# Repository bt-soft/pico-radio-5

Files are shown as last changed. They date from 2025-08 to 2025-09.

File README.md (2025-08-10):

# Pico-Radio-5

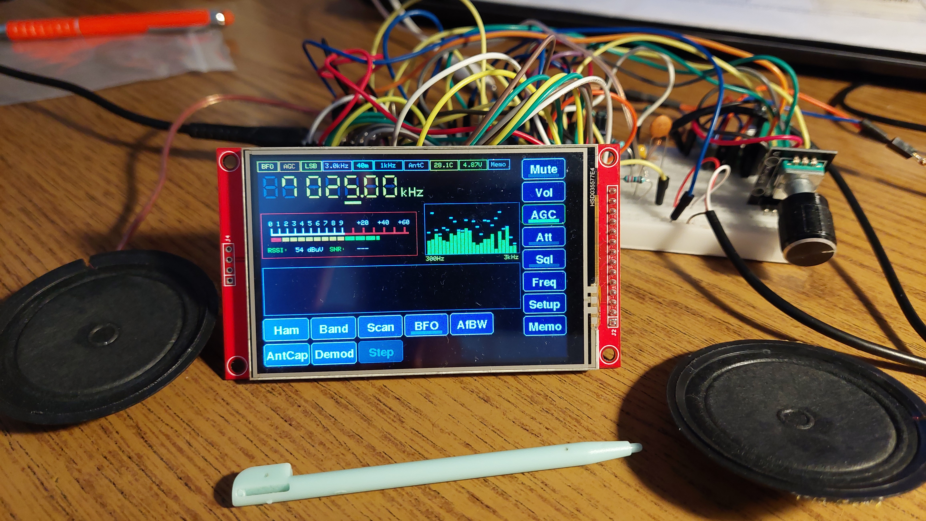
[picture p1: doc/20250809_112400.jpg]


## Hardver részletesen

A Pico-Radio-5 egy fejlett, több sávos rádióvevő, amely a Raspberry Pi Pico (RP2040) mikrokontroller köré épül. A főbb hardverelemek:

- **Raspberry Pi Pico**  
  ARM Cortex-M0+ dual-core MCU, 2MB flash, 264kB RAM, USB programozás.
- **SI4735 rádió IC**  
  Digitális rádióvevő chip, amely támogatja az FM (RDS), AM (MW, LW, SW) sávokat, digitális vezérléssel (I2C).
- **TFT érintőkijelző**  
  320x240 vagy 480x320 felbontású, színes, érintésérzékeny kijelző (TFT_eSPI driverrel).
- **Rotary encoder**  
  Mechanikus forgó kódoló, amely a frekvencia, hangerő, menük vezérlésére szolgál (kattintás érzékelés is).
- **Hangkimenet**  
  3.5mm jack vagy beépített hangszóró, SI4735 audio kimenet közvetlenül vagy erősítőn keresztül.
- **Akkumulátor mérés**  
  Feszültségosztóval a Pico ADC-n keresztül, töltöttség kijelzés.
- **EEPROM**  
  Állomásmemória, beállítások tartós tárolása.
- **Egyéb**  
  Nyomógombok, szenzorok (pl. hőmérséklet), LED-ek, opcionális bővítések.

A részletes kapcsolási rajzok, NYÁK-tervek a `doc/` mappában találhatók:
- [Kapcsolási rajz (PDF)](doc/pico-radio-5-sch.pdf)
- [NYÁK terv (PDF)](doc/pico-radio-5-pcb.pdf)
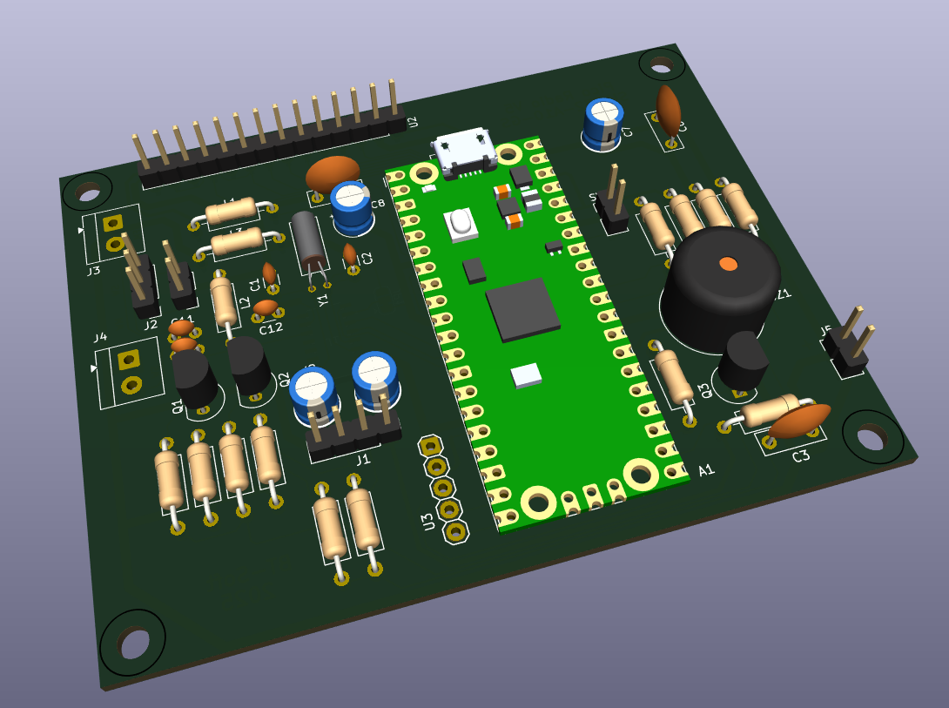
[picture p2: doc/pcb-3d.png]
NYÁK 3D)


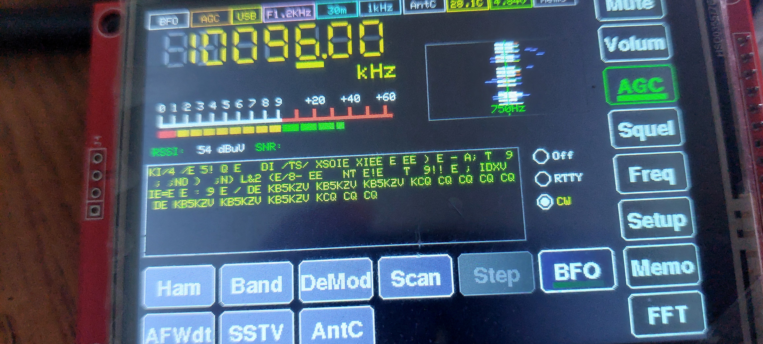
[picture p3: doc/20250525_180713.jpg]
Készülék fotó

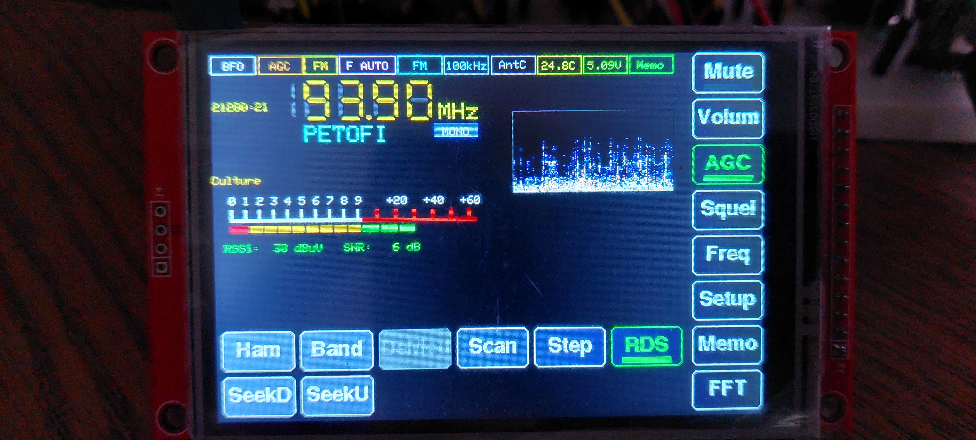
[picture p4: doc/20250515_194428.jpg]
Kijelző példa


## Szoftver részletesen

A szoftver PlatformIO környezetben, C++ nyelven, Arduino frameworkre épül. Főbb könyvtárak: PU2CLR SI4735, TFT_eSPI, RPI_PICO_TimerInterrupt.

### Fő funkciók

- **Rádió sávok**: FM (RDS), AM (MW, LW, SW), SSB/CW támogatás (ha SI4735 patch betöltve)
- **Állomáskeresés, finomhangolás**: automatikus és kézi keresés, lépésköz választás
- **Állomásmemória**: FM/AM/SW/LW sávonként, EEPROM-ban tárolva
- **RDS támogatás**: FM sávban állomásnév, rádiószöveg, PTY, óra
- **Grafikus kezelőfelület**: érintőképernyő, rotary encoder, menük, dialógusok, státuszsor
- **Képernyővédő**: animált frekvencia kijelzés, energiatakarékosság
- **Spektrumkijelzés**: FFT-alapú vizualizáció (ha támogatott)
- **Beállítások**: hangerő, sáv, lépésköz, kijelző fényerő, képernyővédő időzítés, stb.
- **Akkumulátor kijelzés**: töltöttség százalékban, színkódolva
- **Debug és diagnosztika**: soros porton részletes log, hibakereséshez

### Mappastruktúra

- `src/` – Fő forráskód (képernyők, rádió logika, UI, stb.)
- `include/` – Fejlécfájlok, interfészek, konstansok
- `doc/` – Dokumentáció, kapcsolási rajzok, NYÁK-tervek, minták
- `test/` – Egységtesztek, tesztkódok
- `platformio.ini` – PlatformIO projektkonfiguráció

### Főbb forrásfájlok

- `main.cpp` – Inicializálás, fő programciklus
- `ScreenFM.cpp`, `ScreenAM.cpp`, stb. – Különböző rádió sávok kezelői
- `ScreenSaverScreen.cpp` – Képernyővédő logika
- `FreqDisplay.cpp` – Frekvencia kijelző komponens
- `Config.cpp` – Beállítások kezelése, EEPROM mentés/betöltés
- `Si4735Manager.cpp` – SI4735 IC vezérlés, sávváltás, frekvenciaállítás

### Fordítás és feltöltés

1. Telepítsd a PlatformIO-t (ajánlott: VSCode bővítményként)
2. Nyisd meg a projektet VSCode-ban
3. Csatlakoztasd a Raspberry Pi Pico-t USB-n keresztül
4. Válaszd ki a Pico-t mint céleszközt
5. Kattints a Build (vagy Upload) gombra, vagy futtasd:  
   `pio run --target upload`
6. A feltöltés után a rádió automatikusan elindul

### Fejlesztői információk

- A kód moduláris, minden képernyő külön osztályban van
- A beállítások és állomásmemória EEPROM-ban tartósan tárolódik
- A hardveres I2C lábak, rotary encoder, kijelző, stb. pinjei a `pins.h`-ban konfigurálhatók
- Hibakereséshez a soros porton részletes log érhető el

## TFT_eSPI beállítás

A projekt a TFT_eSPI könyvtárat használja a kijelző kezeléséhez. A helyes működéshez a `doc/TFT_eSPI/User_Setup.h` fájlt be kell másolni a PlatformIO által használt TFT_eSPI könyvtár megfelelő mappájába. Ez általában:

```
.pio/libdeps/pico/TFT_eSPI/User_Setup.h
```

A másolás után a kijelző a projektben definiált beállításokkal fog működni. Ha másik kijelzőt használsz, módosítsd a `User_Setup.h`-t a saját hardveredhez.

## Licenc

A projekt szabadon felhasználható, módosítható, forrásmegjelöléssel. Lásd a forráskód fejléceit.

---

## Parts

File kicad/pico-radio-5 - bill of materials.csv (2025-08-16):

Id | Designator | Footprint | Quantity | Designation | Supplier and ref
1 | Q3,Q1,Q2 | TO-92_Inline | 3 | PN2222A
2 | L1,L3 | R_Axial_DIN0207_L6.3mm_D2.5mm_P10.16mm_Horizontal | 2 | 47uH
3 | C9,C6,C3 | C_Disc_D7.0mm_W2.5mm_P5.00mm | 3 | 100nF
4 | C8,C7,C5,C4 | CP_Radial_D5.0mm_P2.50mm | 4 | 4.7uF
5 | SW1 | PinHeader_1x02_P2.54mm_Vertical | 1 | Reset
6 | J2 | PinHeader_1x03_P2.54mm_Vertical | 1 | MW/SW antenna
7 | R3,R4 | R_Axial_DIN0207_L6.3mm_D2.5mm_P10.16mm_Horizontal | 2 | 22k
8 | L2 | R_Axial_DIN0207_L6.3mm_D2.5mm_P10.16mm_Horizontal | 1 | 270uH
9 | JP2 | R_Axial_DIN0207_L6.3mm_D2.5mm_P10.16mm_Horizontal | 1 | NYÁK átkötés
10 | R7,R10,R11,R9,R8 | R_Axial_DIN0207_L6.3mm_D2.5mm_P10.16mm_Horizontal | 5 | 4.7k
11 | C2,C1 | C_Disc_D3.0mm_W1.6mm_P2.50mm | 2 | 22pF
12 | U2 | PinHeader_1x14_P2.54mm_Vertical | 1 | TFT_320x240
13 | J3 | TerminalBlock_4Ucon_1x02_P3.50mm_Horizontal | 1 | FM antenna
14 | J1 | PinHeader_1x04_P2.54mm_Vertical | 1 | HF Amplifier
15 | Y1 | Crystal_C38-LF_D3.0mm_L8.0mm_Horizontal | 1 | 32.762kHz
16 | J5 | PinHeader_1x02_P2.54mm_Vertical | 1 | Batterry
17 | C12,C11 | C_Disc_D3.0mm_W1.6mm_P2.50mm | 2 | 1nF
18 | L4 | PinHeader_1x02_P2.54mm_Vertical | 1 | 30uH (MW Ferrite antenna)
19 | R5,R6 | R_Axial_DIN0207_L6.3mm_D2.5mm_P10.16mm_Horizontal | 2 | 10k
20 | J4 | TerminalBlock_4Ucon_1x02_P3.50mm_Horizontal | 1 | SW antenna
21 | U3 | KY-040-PORT | 1 | KY-040
22 | R1 | R_Axial_DIN0207_L6.3mm_D2.5mm_P10.16mm_Horizontal | 1 | 200k
23 | A1 | RaspberryPi_Pico_Common_THT-simple | 1 | RaspberryPi_Pico - purple
24 | BZ1 | Buzzer_12x9.5RM7.6 | 1 | Buzzer
25 | C10 | C_Disc_D3.0mm_W1.6mm_P2.50mm | 1 | 33pF
26 | R2 | R_Axial_DIN0207_L6.3mm_D2.5mm_P10.16mm_Horizontal | 1 | 100k
27 | U1 | SOIC_A10-GS_SIL | 1 | SI4732-A10-GS

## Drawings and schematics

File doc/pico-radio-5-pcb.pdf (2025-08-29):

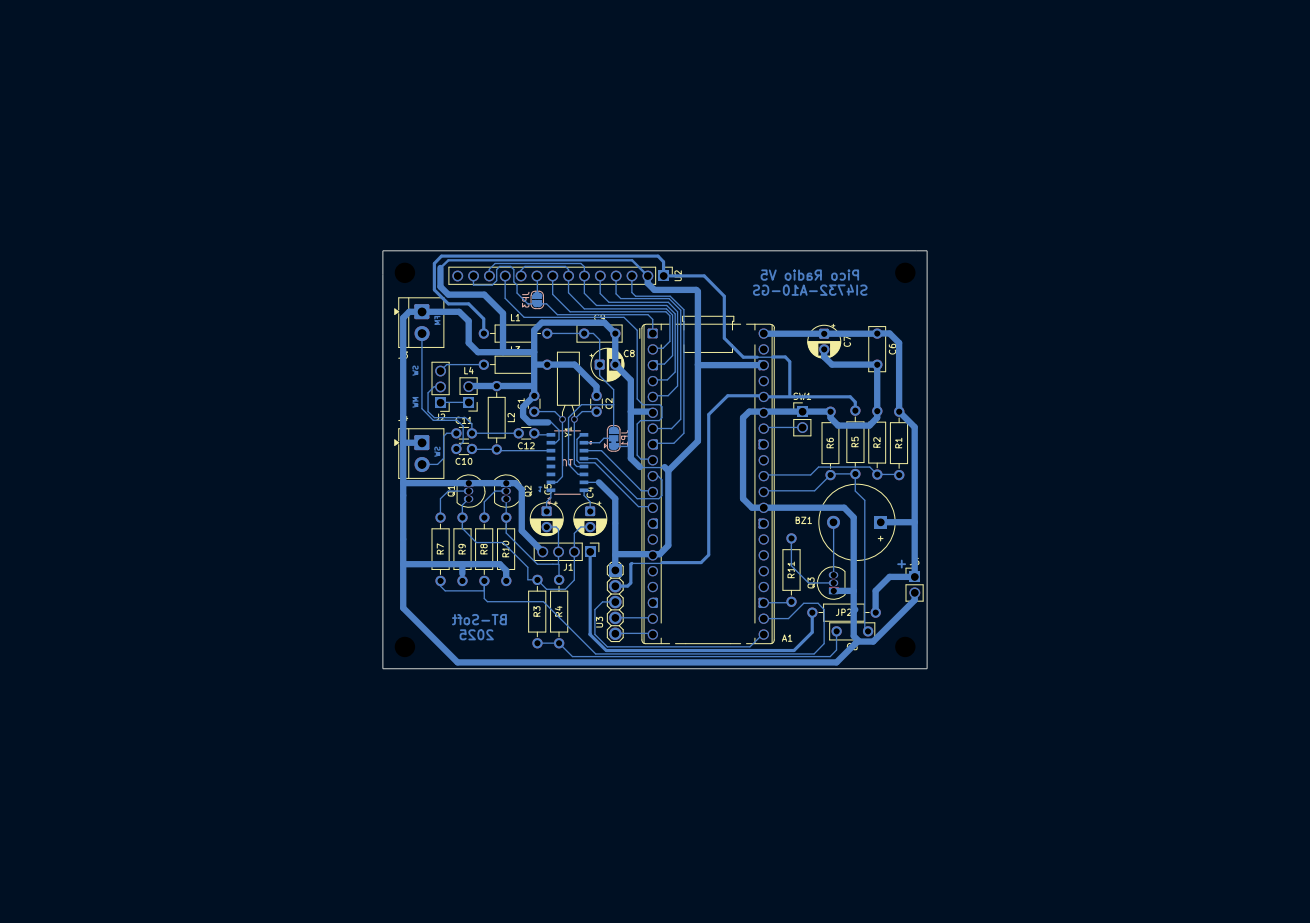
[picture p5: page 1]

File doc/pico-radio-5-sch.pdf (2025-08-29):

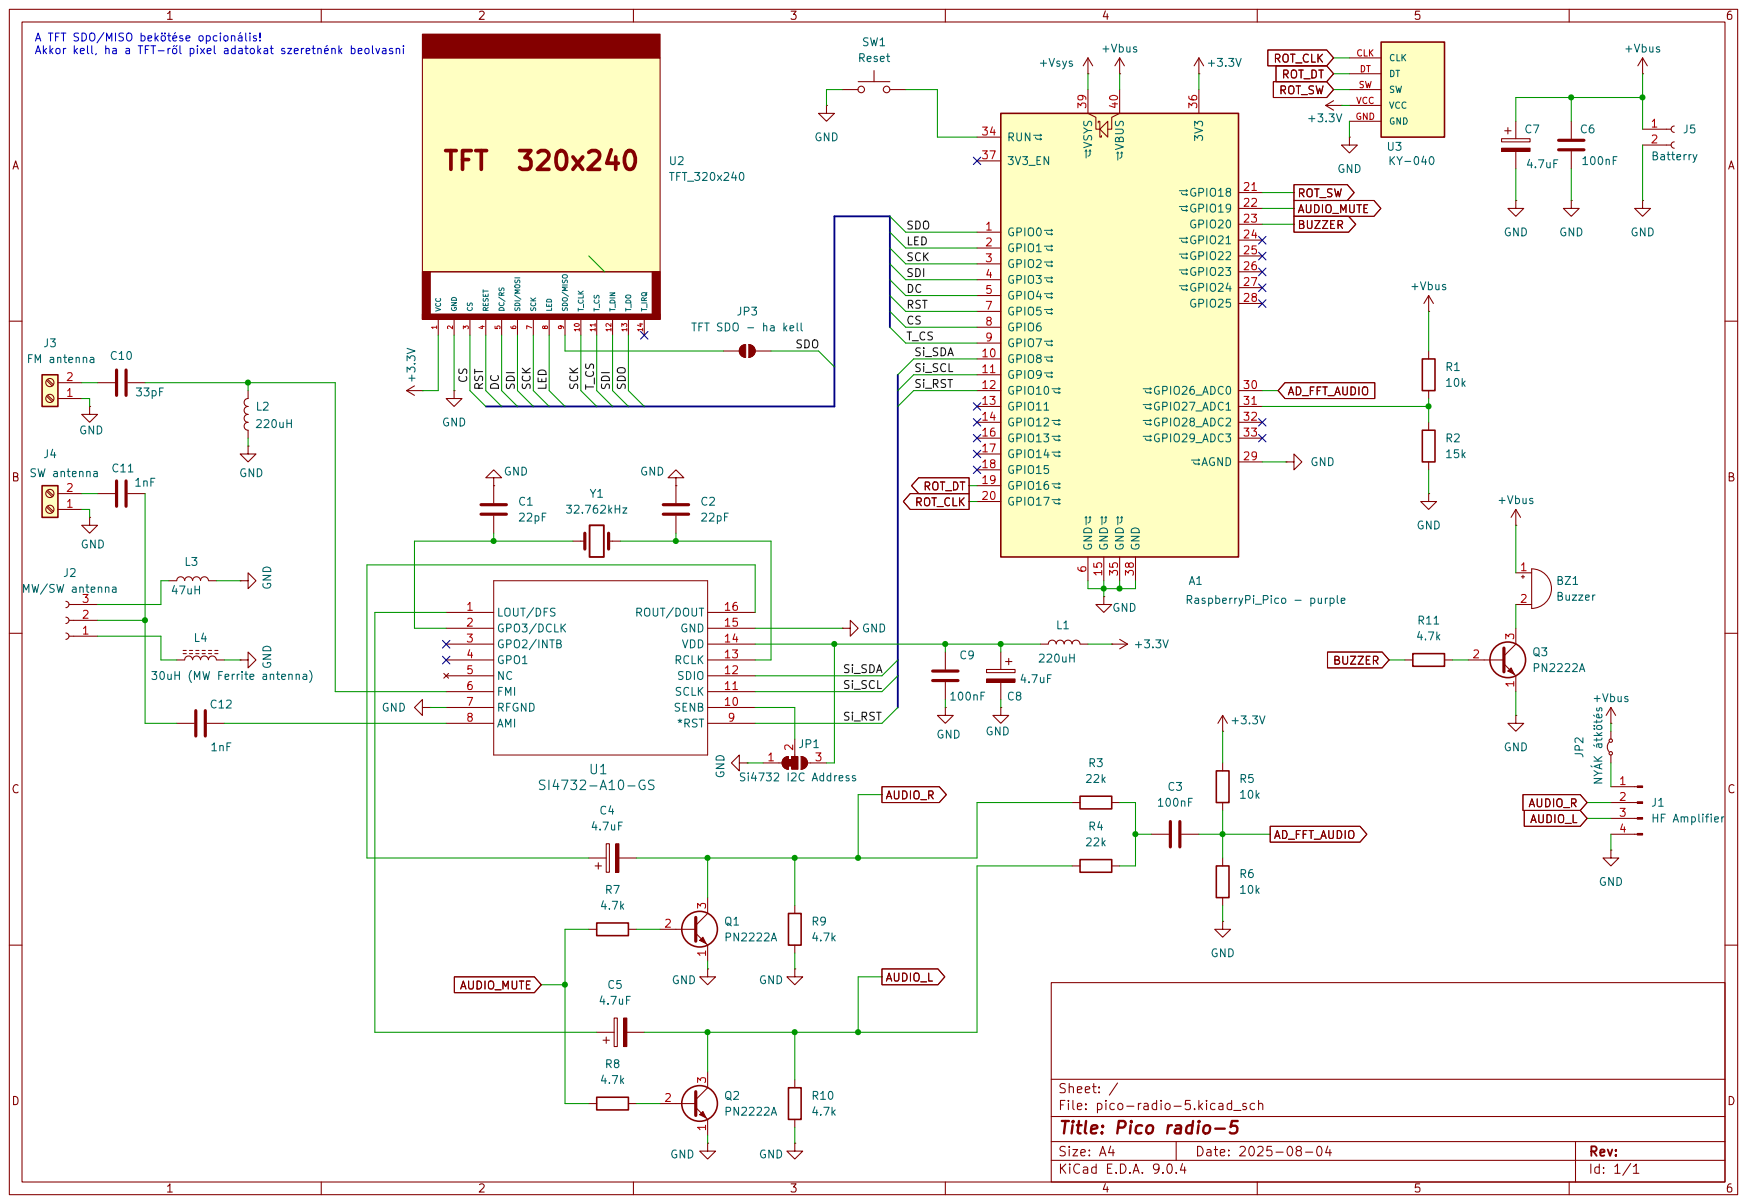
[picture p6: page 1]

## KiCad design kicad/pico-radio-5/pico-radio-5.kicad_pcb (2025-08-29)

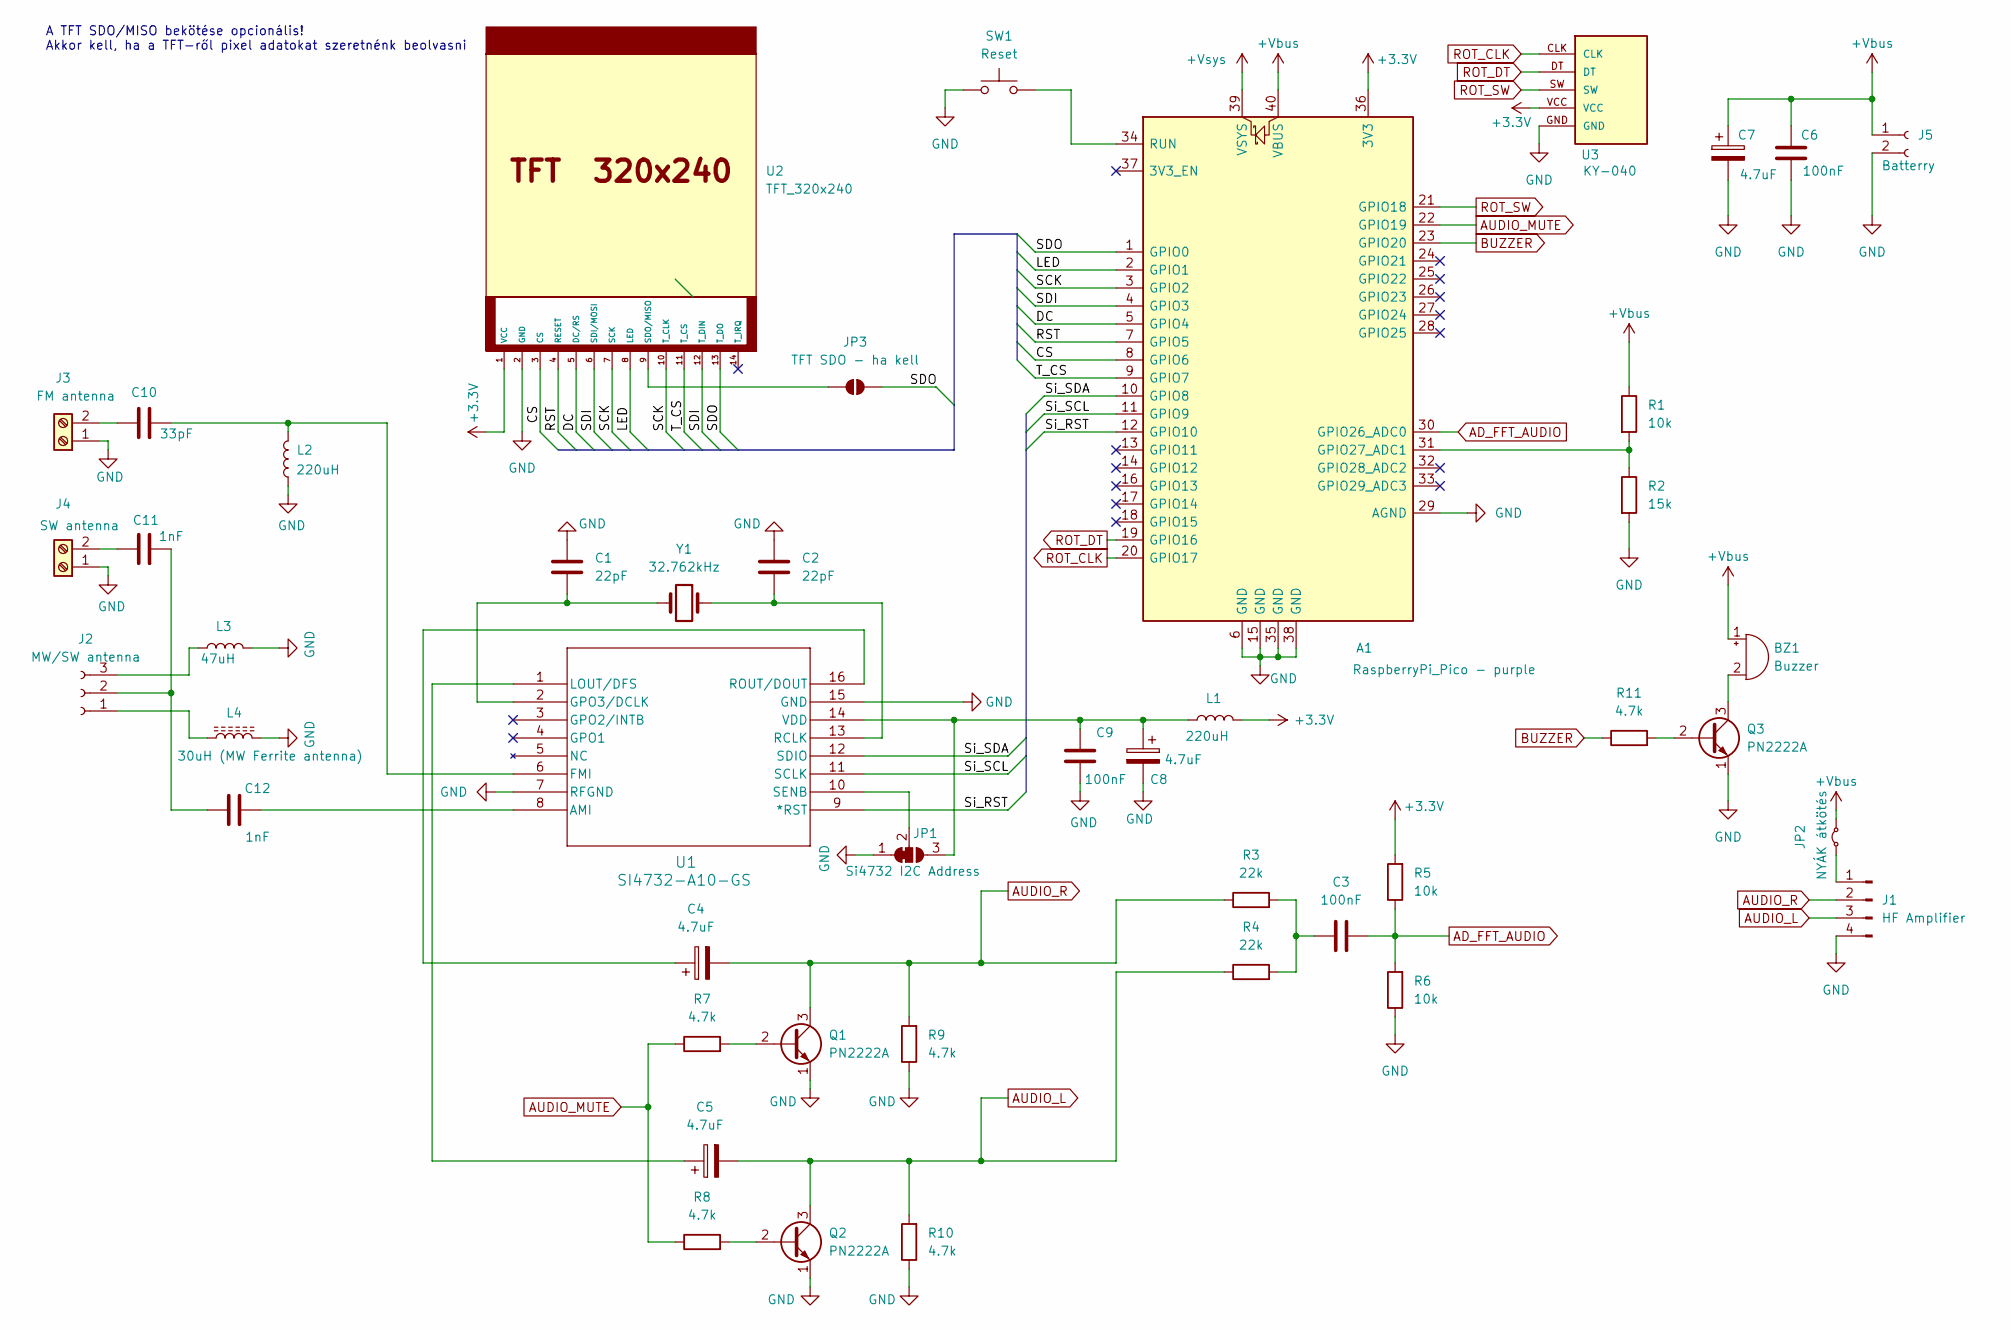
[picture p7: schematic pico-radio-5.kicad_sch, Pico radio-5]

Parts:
A1: RaspberryPi_Pico - purple; RaspberryPi_Pico_Common_THT-simple
BZ1: Buzzer; Buzzer_12x9.5RM7.6
C1, C2: 22pF; C_Disc_D3.0mm_W1.6mm_P2.50mm
C3, C6, C9: 100nF; C_Disc_D7.0mm_W2.5mm_P5.00mm
C4, C5, C7, C8: 4.7uF; CP_Radial_D5.0mm_P2.50mm
C10: 33pF; C_Disc_D3.0mm_W1.6mm_P2.50mm
C11, C12: 1nF; C_Disc_D3.0mm_W1.6mm_P2.50mm
J1: HF Amplifier; PinHeader_1x04_P2.54mm_Vertical
J2: MW/SW antenna; PinHeader_1x03_P2.54mm_Vertical
J3: FM antenna; TerminalBlock_4Ucon_1x02_P3.50mm_Horizontal
J4: SW antenna; TerminalBlock_4Ucon_1x02_P3.50mm_Horizontal
J5: Batterry; PinHeader_1x02_P2.54mm_Vertical
JP1: Si4732 I2C Address; SolderJumper-3_P1.3mm_Bridged12_RoundedPad1.0x1.5mm
JP2: NYÁK átkötés; R_Axial_DIN0207_L6.3mm_D2.5mm_P10.16mm_Horizontal
JP3: TFT SDO - ha kell; SolderJumper-2_P1.3mm_Open_RoundedPad1.0x1.5mm
L1, L2: 220uH; R_Axial_DIN0207_L6.3mm_D2.5mm_P10.16mm_Horizontal
L3: 47uH; R_Axial_DIN0207_L6.3mm_D2.5mm_P10.16mm_Horizontal
L4: 30uH (MW Ferrite antenna); PinHeader_1x02_P2.54mm_Vertical
Q1, Q2, Q3: PN2222A; TO-92_Inline
R1, R5, R6: 10k; R_Axial_DIN0207_L6.3mm_D2.5mm_P10.16mm_Horizontal
R2: 15k; R_Axial_DIN0207_L6.3mm_D2.5mm_P10.16mm_Horizontal
R3, R4: 22k; R_Axial_DIN0207_L6.3mm_D2.5mm_P10.16mm_Horizontal
R7, R8, R9, R10, R11: 4.7k; R_Axial_DIN0207_L6.3mm_D2.5mm_P10.16mm_Horizontal
SW1: Reset; PinHeader_1x02_P2.54mm_Vertical
U1: SI4732-A10-GS; SOIC_A10-GS_SIL
U2: TFT_320x240; PinHeader_1x14_P2.54mm_Vertical
U3: KY-040; KY-040-PORT
Y1: 32.762kHz; Crystal_C38-LF_D3.0mm_L8.0mm_Horizontal

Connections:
+3.3V: A1.36 (3V3), L1.2, R5.2, U2.1 (VCC), U3.VCC
+Vbus: A1.40 (VBUS), BZ1.1 (+), C6.1, C7.1, J5.1, JP2.2 (B), R1.1
+Vsys: A1.39 (VSYS)
/CS: A1.8 (GPIO6), U2.3 (CS)
/DC: A1.5 (GPIO4), U2.5 (DC/RS)
/LED: A1.2 (GPIO1), U2.8 (LED)
/RST: A1.7 (GPIO5), U2.4 (RESET)
/SCK: A1.3 (GPIO2), U2.7 (SCK), U2.10 (T_CLK)
/SDI: A1.4 (GPIO3), U2.6 (SDI/MOSI), U2.12 (T_DIN)
/SDO: A1.1 (GPIO0), JP3.2 (B), U2.13 (T_DO)
/Si_RST: A1.12 (GPIO10), U1.9 (*RST)
/Si_SCL: A1.11 (GPIO9), U1.11 (SCLK)
/Si_SDA: A1.10 (GPIO8), U1.12 (SDIO)
/T_CS: A1.9 (GPIO7), U2.11 (T_CS)
AD_FFT_AUDIO: A1.30 (GPIO26_ADC0), C3.2, R5.1, R6.2
AUDIO_L: C5.2, J1.3, Q2.3 (C), R4.1, R10.2
AUDIO_MUTE: A1.22 (GPIO19), R7.1, R8.1
AUDIO_R: C4.2, J1.2, Q1.3 (C), R3.1, R9.2
BUZZER: A1.23 (GPIO20), R11.1
GND: A1.6 (GND), A1.15 (GND), A1.29 (AGND), A1.35 (GND), A1.38 (GND), C1.2, C2.1, C6.2, C7.2, C8.2, C9.1, J1.4, J3.1, J4.1, J5.2, JP1.1 (A), L2.1, L3.2, L4.2, Q1.1 (E), Q2.1 (E), Q3.1 (E), R2.2, R6.1, R9.1, R10.1, SW1.1, U1.7 (RFGND), U1.15 (GND), U2.2 (GND), U3.GND
unnamed: A1.31 (GPIO27_ADC1), R1.2, R2.1
unnamed: A1.34 (RUN), SW1.2
unnamed: BZ1.2 (-), Q3.3 (C)
unnamed: C3.1, R3.2, R4.2
unnamed: J1.1, JP2.1 (A)
unnamed: J2.1, L4.1
unnamed: C11.2, C12.2, J2.2
unnamed: J2.3, L3.1
unnamed: C10.2, J3.2
unnamed: C11.1, J4.2
unnamed: C8.1, C9.2, JP1.3 (B), L1.1, U1.14 (VDD)
unnamed: JP1.2 (C), U1.10 (SENB)
unnamed: JP3.1 (A), U2.9 (SDO/MISO)
unnamed: Q1.2 (B), R7.2
unnamed: Q2.2 (B), R8.2
unnamed: Q3.2 (B), R11.2
unnamed: C12.1, U1.8 (AMI)
unnamed: C10.1, L2.2, U1.6 (FMI)
unnamed: C1.1, U1.2 (GPO3/DCLK), Y1.2
unnamed: C5.1, U1.1 (LOUT/DFS)
unnamed: C2.2, U1.13 (RCLK), Y1.1
unnamed: C4.1, U1.16 (ROUT/DOUT)
ROT_CLK: A1.20 (GPIO17), U3.CLK
ROT_DT: A1.19 (GPIO16), U3.DT
ROT_SW: A1.21 (GPIO18), U3.SW

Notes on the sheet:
A TFT SDO/MISO bekötése opcionális! Akkor kell, ha a TFT-ről pixel adatokat szeretnénk beolvasni

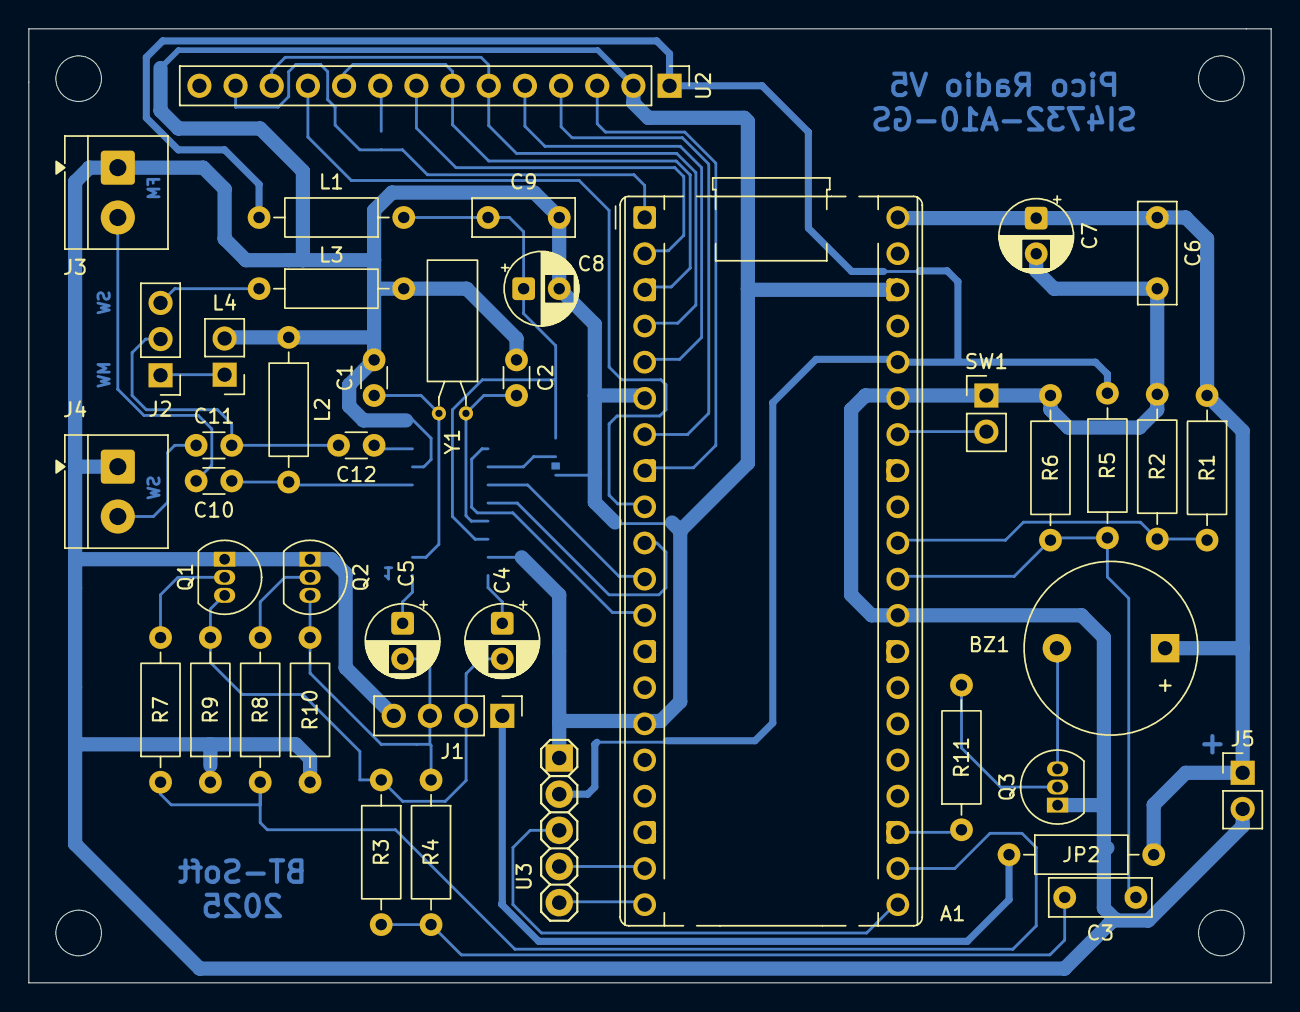
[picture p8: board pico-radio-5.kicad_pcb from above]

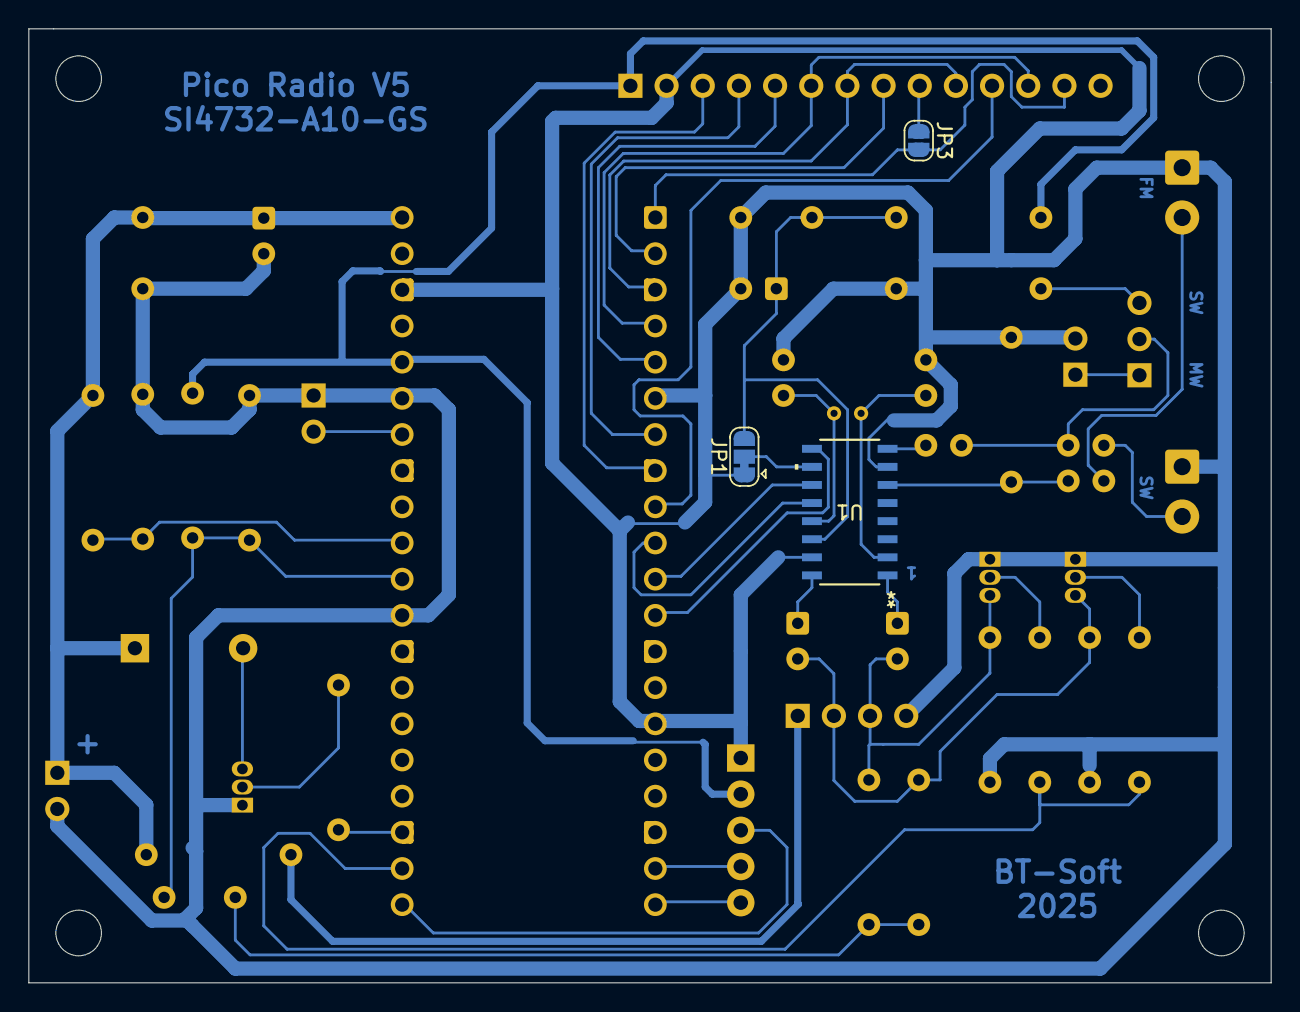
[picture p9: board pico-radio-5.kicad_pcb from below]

Board: 2 copper layers, 87.2 x 67.0 mm, 45 parts (3 on the bottom side), 44 nets.

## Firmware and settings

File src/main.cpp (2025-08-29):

#include <Arduino.h>

#include "PicoMemoryInfo.h"
#include "PicoSensorUtils.h"
#include "SplashScreen.h"

//-------------------- Config
#include "AudioCore1Manager.h"
#include "AudioProcessor.h"
#include "BandStore.h"
#include "Config.h"
#include "EepromLayout.h"
#include "StationStore.h"
#include "StoreEepromBase.h"
extern Config config;
extern FmStationStore fmStationStore;
extern AmStationStore amStationStore;
extern BandStore bandStore;

//------------------- Rotary Encoder
#include <RPi_Pico_TimerInterrupt.h>
RPI_PICO_Timer rotaryTimer(0); // 0-ás timer használata
#include "RotaryEncoder.h"
RotaryEncoder rotaryEncoder = RotaryEncoder(PIN_ENCODER_CLK, PIN_ENCODER_DT, PIN_ENCODER_SW, ROTARY_ENCODER_STEPS_PER_NOTCH);
#define ROTARY_ENCODER_SERVICE_INTERVAL_IN_MSEC 1 // 1msec

// A CW/RTTY dekóderhez szükséges
RPI_PICO_Timer audioDecoderTimer(1); // 1-es timer használata

//------------------ TFT
#include <TFT_eSPI.h>
TFT_eSPI tft;
uint16_t SCREEN_W;
uint16_t SCREEN_H;

//------------------ SI4735
#include "Band.h" // Band típusok konstansaihoz
#include "Si4735Manager.h"
Si4735Manager *pSi4735Manager = nullptr; // Si4735Manager: NEM lehet (hardware inicializálás miatt) statikus, mert HW inicializálások is vannak benne

//-------------------- Screens
// Globális képernyőkezelő pointer - inicializálás a setup()-ban történik
#include "ScreenManager.h"
ScreenManager *screenManager = nullptr;
IScreenManager **iScreenManager = (IScreenManager **)&screenManager; // A UIComponent használja

// -----------------------------------------------------------------------------

/**
 * @brief  Hardware timer interrupt service routine a rotaryhoz
 */
bool rotaryTimerHardwareInterruptHandler(struct repeating_timer *t) {
    rotaryEncoder.service();
    return true;
}

// -----------------------------------------------------------------------------

//-

/**
 * @brief Program belépési pont.
 */
void setup() {
#ifdef __DEBUG
    Serial.begin(115200);
#endif

    // PICO AD inicializálása
    PicoSensorUtils::init();

    // Beeper
    pinMode(PIN_BEEPER, OUTPUT);
    digitalWrite(PIN_BEEPER, LOW);

    // TFT LED háttérvilágítás kimenet
    pinMode(PIN_TFT_BACKGROUND_LED, OUTPUT);
    Utils::setTftBacklight(TFT_BACKGROUND_LED_MAX_BRIGHTNESS); // TFT inicializálása DC módban
    tft.init();
    tft.setRotation(1);
    tft.fillScreen(TFT_BLACK); // Fekete háttér a splash screen-hez

    // UI komponensek számára képernyő méretek inicializálása
    SCREEN_W = tft.width();
    SCREEN_H = tft.height();

#ifdef DEBUG_WAIT_FOR_SERIAL
    Utils::debugWaitForSerial(tft);
#endif

    // Csak az általános információkat jelenítjük meg először (SI4735 nélkül)
    // Program cím és build info megjelenítése
    tft.setFreeFont();
    tft.setTextSize(2);
    tft.setTextColor(TFT_CYAN, TFT_BLACK);
    tft.setTextDatum(TC_DATUM);
    tft.drawString(PROGRAM_NAME, tft.width() / 2, 20);

    tft.setTextSize(1);
    tft.setTextColor(TFT_WHITE, TFT_BLACK);
    tft.setTextDatum(TC_DATUM);
    tft.drawString("Version " + String(PROGRAM_VERSION), tft.width() / 2, 50);
    tft.drawString(PROGRAM_AUTHOR, tft.width() / 2, 70);

    // Build info
    tft.setTextColor(TFT_YELLOW, TFT_BLACK);
    tft.setTextDatum(TC_DATUM);
    tft.drawString("Build: " + String(__DATE__) + " " + String(__TIME__), tft.width() / 2, 100);

    // Inicializálási progress
    tft.setTextColor(TFT_GREEN, TFT_BLACK);
    tft.setTextDatum(TC_DATUM);
    tft.drawString("Initializing...", tft.width() / 2, 140);

    // EEPROM inicializálása (A fordítónak muszáj megadni egy típust, itt most egy Config_t-t használunk, igaziból mindegy)
    tft.drawString("Loading EEPROM...", tft.width() / 2, 160);
    StoreEepromBase<Config_t>::init(); // Meghívjuk a statikus init metódust

    // Ha a bekapcsolás alatt nyomva tartjuk a rotary gombját, akkor töröljük a konfigot
    if (digitalRead(PIN_ENCODER_SW) == LOW) {
        DEBUG("Encoder button pressed during startup, restoring defaults...\n");
        Utils::beepTick();
        delay(1500);
        if (digitalRead(PIN_ENCODER_SW) == LOW) { // Ha még mindig nyomják

            DEBUG("Restoring default settings...\n");
            Utils::beepTick();
            config.loadDefaults();
            fmStationStore.loadDefaults();
            amStationStore.loadDefaults();
            bandStore.loadDefaults();

            DEBUG("Save default settings...\n");
            Utils::beepTick();
            config.checkSave();
            bandStore.checkSave(); // Band adatok mentése
            fmStationStore.checkSave();
            amStationStore.checkSave();

            Utils::beepTick();
            DEBUG("Default settings restored!\n");
        }
    } else {
        // konfig betöltése
        tft.drawString("Loading config...", tft.width() / 2, 180);
        config.load();
    }

    // Rotary Encoder beállítása
    rotaryEncoder.setDoubleClickEnabled(true);                                  // Dupla kattintás engedélyezése
    rotaryEncoder.setAccelerationEnabled(config.data.rotaryAcceleratonEnabled); // Gyorsítás engedélyezése a rotary enkóderhez
    // Pico HW Timer1 beállítása a rotaryhoz
    rotaryTimer.attachInterruptInterval(ROTARY_ENCODER_SERVICE_INTERVAL_IN_MSEC * 1000, rotaryTimerHardwareInterruptHandler);

    // Kell kalibrálni a TFT Touch-t?
    if (Utils::isZeroArray(config.data.tftCalibrateData)) {
        Utils::beepError();
        Utils::tftTouchCalibrate(tft, config.data.tftCalibrateData);
    }

    // Beállítjuk a touch scren-t
    tft.setTouch(config.data.tftCalibrateData);

    // Állomáslisták és band adatok betöltése az EEPROM-ból (a config után!)
    tft.drawString("Loading stations & bands...", tft.width() / 2, 200);
    bandStore.load(); // Band adatok betöltése
    fmStationStore.load();
    amStationStore.load();

    // Splash screen megjelenítése inicializálás közben
    // Most átváltunk a teljes splash screen-re az SI4735 infókkal
    SplashScreen *splash = new SplashScreen(tft);
    splash->show(true, 8);

    // Splash screen megjelenítése progress bar-ral    // Lépés 1: I2C inicializálás
    splash->updateProgress(1, 9, "Initializing I2C...");

    // Az si473x (Nem a default I2C lábakon [4,5] van!!!)
    Wire.setSDA(PIN_SI4735_I2C_SDA); // I2C for SI4735 SDA
    Wire.setSCL(PIN_SI4735_I2C_SCL); // I2C for SI4735 SCL
    Wire.begin();
    delay(300);

    // Si4735Manager inicializálása itt
    splash->updateProgress(2, 9, "Initializing SI4735 Manager...");
    if (pSi4735Manager == nullptr) {
        pSi4735Manager = new Si4735Manager();
        // BandStore beállítása a Si4735Manager-ben
        pSi4735Manager->setBandStore(&bandStore);
    }

    // KRITIKUS: Band tábla dinamikus adatainak EGYSZERI inicializálása RÖGTÖN a Si4735Manager létrehozása után!
    pSi4735Manager->initializeBandTableData(true); // forceReinit = true az első inicializálásnál

    // Si4735 inicializálása
    splash->updateProgress(3, 9, "Detecting SI4735...");
    int16_t si4735Addr = pSi4735Manager->getDeviceI2CAddress();
    if (si4735Addr == 0) {
        Utils::beepError();
        tft.fillScreen(TFT_BLACK);
        tft.setTextColor(TFT_RED, TFT_BLACK);
        tft.setTextSize(2);
        tft.setTextDatum(MC_DATUM);
        tft.drawString("SI4735 NOT DETECTED!", tft.width() / 2, tft.height() / 2);
        DEBUG("Si4735 not detected");
        while (true) // nem megyünk tovább
            ;
    } // Lépés 4: SI4735 konfigurálás
    splash->updateProgress(4, 6, "Configuring SI4735...");
    pSi4735Manager->setDeviceI2CAddress(si4735Addr == 0x11 ? 0 : 1); // Sets the I2C Bus Address, erre is szükség van...    splash->drawSI4735Info(si4735Manager->getSi4735());

    delay(300);
    //--------------------------------------------------------------------

    // Lépés 5: Frekvencia beállítások
    splash->updateProgress(4, 9, "Setting up radio...");
    pSi4735Manager->init(true);
    pSi4735Manager->getSi4735().setVolume(config.data.currVolume); // Hangerő visszaállítása

    delay(100);

    // Kezdő képernyőtípus beállítása
    splash->updateProgress(5, 9, "Preparing display...");
    const char *startScreenName = pSi4735Manager->getCurrentBandType() == FM_BAND_TYPE ? SCREEN_NAME_FM : SCREEN_NAME_AM;
    delay(100);

    //--------------------------------------------------------------------
    // Lépés 7: Core1 Audio Manager inicializálása
    splash->updateProgress(6, 9, "Starting Core1 audio processor...");

    // Core1 Audio Manager inicializálása a megfelelő FFT gain referenciákkal
    bool core1InitSuccess = AudioCore1Manager::init(config.data.audioFftConfigAm,                           // AM FFT gain referencia
                                                    config.data.audioFftConfigFm,                           // FM FFT gain referencia
                                                    PIN_AUDIO_INPUT,                                        // Audio bemenet pin
                                                    AudioProcessorConstants::DEFAULT_FM_SAMPLING_FREQUENCY, // Mintavételezési frekvencia, FM -> 30kHz
                                                    AudioProcessorConstants::DEFAULT_FFT_SAMPLES            // Kezdeti FFT méret -> 512
    );
    if (!core1InitSuccess) {
        DEBUG("HIBA: A Core1 Audio Manager inicializálás sikertelen!\n");
        Utils::beepError();
        // Folytatjuk anélkül is, de spectrum nem fog működni
    }

    delay(100);

    // Lépés 8: ScreenManager inicializálása
    splash->updateProgress(7, 9, "Preparing display...");

    // ScreenManager inicializálása itt, amikor minden más már kész
    if (screenManager == nullptr) {
        screenManager = new ScreenManager();
    }

    screenManager->switchToScreen(startScreenName); // A kezdő képernyő

    delay(100);

    // Lépés 9: Finalizálás
    splash->updateProgress(8, 9, "Starting up...");

    delay(100); // Rövidebb delay

    splash->updateProgress(9, 9, "Starting OK");

    delay(100); // Rövidebb delay

    // Splash screen eltűntetése
    splash->hide();

    //--------------------------------------------------------------------

    // SplashScreen törlése, már nincs rá szükség
    delete splash;

    // Csippantunk egyet
    Utils::beepTick();
}

/**
 * @brief Fő ciklus
 */
void loop() {

//------------------- EEPROM mentés figyelése
#define EEPROM_SAVE_CHECK_INTERVAL 1000 * 60 * 5 // 5 perc
    static uint32_t lastEepromSaveCheck = 0;
    if (millis() - lastEepromSaveCheck >= EEPROM_SAVE_CHECK_INTERVAL) {
        config.checkSave();
        bandStore.checkSave(); // Band adatok mentése
        fmStationStore.checkSave();
        amStationStore.checkSave();
        lastEepromSaveCheck = millis();
    }
//------------------- Memória információk megjelenítése
#ifdef SHOW_MEMORY_INFO
    static uint32_t lasDebugMemoryInfo = 0;
    if (millis() - lasDebugMemoryInfo >= MEMORY_INFO_INTERVAL) {
        PicoMemoryInfo::debugMemoryInfo();
        lasDebugMemoryInfo = millis();
    }
#endif
    //------------------- Touch esemény kezelése
    uint16_t touchX, touchY;
    bool touchedRaw = tft.getTouch(&touchX, &touchY);
    bool validCoordinates = true;
    if (touchedRaw) {
        if (touchX > tft.width() || touchY > tft.height()) {
            validCoordinates = false;
        }
    }

    static bool lastTouchState = false;
    static uint16_t lastTouchX = 0, lastTouchY = 0;
    bool touched = touchedRaw && validCoordinates;

    // Touch press event (immediate response)
    if (touched && !lastTouchState) {
        TouchEvent touchEvent(touchX, touchY, true);
        screenManager->handleTouch(touchEvent);
        lastTouchX = touchX;
        lastTouchY = touchY;
    } else if (!touched && lastTouchState) { // Touch release event (immediate response)
        TouchEvent touchEvent(lastTouchX, lastTouchY, false);
        screenManager->handleTouch(touchEvent);
    }

    lastTouchState = touched;

    //------------------- Rotary Encoder esemény kezelése
    // Rotary Encoder olvasása
    RotaryEncoder::EncoderState encoderState = rotaryEncoder.read();

    // Rotary encoder eseményeinek továbbítása a ScreenManager-nek
    if (encoderState.direction != RotaryEncoder::Direction::None || encoderState.buttonState != RotaryEncoder::ButtonState::Open) {

        // RotaryEvent létrehozása a ScreenManager típusaival
        RotaryEvent::Direction direction = RotaryEvent::Direction::None;
        if (encoderState.direction == RotaryEncoder::Direction::Up) {
            direction = RotaryEvent::Direction::Up;
        } else if (encoderState.direction == RotaryEncoder::Direction::Down) {
            direction = RotaryEvent::Direction::Down;
        }

        RotaryEvent::ButtonState buttonState = RotaryEvent::ButtonState::NotPressed;
        if (encoderState.buttonState == RotaryEncoder::ButtonState::Clicked) {
            buttonState = RotaryEvent::ButtonState::Clicked;
        } else if (encoderState.buttonState == RotaryEncoder::ButtonState::DoubleClicked) {
            buttonState = RotaryEvent::ButtonState::DoubleClicked;
        }

        // Esemény továbbítása a ScreenManager-nek
        RotaryEvent rotaryEvent(direction, buttonState, encoderState.value);
        if (screenManager) {
            screenManager->handleRotary(rotaryEvent);
        }
        // bool handled = screenManager->handleRotary(rotaryEvent);
        // DEBUG("Rotary event handled by screen: %s\n", handled ? "YES" : "NO");
    }

    if (screenManager) {
        // Deferred actions feldolgozása - biztonságos képernyőváltások végrehajtása
        screenManager->loop();
    }

    // SI4735 loop hívása, squelch és hardver némítás kezelése
    if (pSi4735Manager) {
        pSi4735Manager->loop();
    }

    // // Core1 Audio Manager debug információk kiírása
    // static uint32_t lasAudioCore1ManagerDebugInfo = 0;
    // if (millis() - lasAudioCore1ManagerDebugInfo >= 10 * 1000) {
    //     AudioCore1Manager::debugInfo(); // Core1 Audio Manager debug info kiírása
    //     lasAudioCore1ManagerDebugInfo = millis();
    // }
}

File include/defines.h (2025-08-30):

#pragma once

#include <Arduino.h>

#include "pins.h"

//---- Program Information ------------------------------------------

#define PROGRAM_NAME "Pico Radio v5"
#define PROGRAM_VERSION "0.0.5"
#define PROGRAM_AUTHOR "bt-soft"

//---- Program Information ------------------------------------------

//--- ScreenNames ----
#define SCREEN_NAME_FM "ScreenFM"
#define SCREEN_NAME_AM "ScreenAM"
#define SCREEN_NAME_SCREENSAVER "SaverScreen"
#define SCREEN_NAME_SETUP "ScreenSetup"
#define SCREEN_NAME_SETUP_SYSTEM "ScreenSetupSystem"
#define SCREEN_NAME_SETUP_SI4735 "ScreenSetupSi4735"
#define SCREEN_NAME_SETUP_AUDIO_PROC "ScreenSetupAudioProc"

#define SCREEN_NAME_MEMORY "ScreenMemory"
#define SCREEN_NAME_SCAN "ScreenScan"

#define SCREEN_NAME_TEST "TestScreen"
#define SCREEN_NAME_EMPTY "EmptyScreen"

//--- Debug ---
#define __DEBUG // Debug mód vezérlése

#ifdef __DEBUG
// #define SHOW_MEMORY_INFO
#define MEMORY_INFO_INTERVAL 20 * 1000 // 20mp

// Soros portra várakozás a debug üzenetek előtt
// #define DEBUG_WAIT_FOR_SERIAL

// Debug keretek rajzolása a UI komponensek köré
// #define DRAW_DEBUG_GUI_FRAMES

#endif

// Feszültségmérés
#define VBUS_DIVIDER_R1 10.0f // Ellenállás VBUS és A0 között (kOhm)
#define VBUS_DIVIDER_R2 15.0f // Ellenállás A0 és GND között (kOhm)

// Rotary Encoder
#define __USE_ROTARY_ENCODER_IN_HW_TIMER

// TFT háttérvilágítás max érték
#define TFT_BACKGROUND_LED_MAX_BRIGHTNESS 255
#define TFT_BACKGROUND_LED_MIN_BRIGHTNESS 5

//--- Battery ---
#define MIN_BATTERY_VOLTAGE 270 // Minimum akkumulátor feszültség (V*100)
#define MAX_BATTERY_VOLTAGE 405 // Maximum akkumulátor feszültség (V*100)

//--- ScreenSaver
#define SCREEN_SAVER_TIMEOUT_MIN 1
#define SCREEN_SAVER_TIMEOUT_MAX 60
#define SCREEN_SAVER_TIMEOUT 10 // 1 perc a képernyővédő időzítése - tesztelés

//--- CW Decoder ---
#define CW_DECODER_DEFAULT_FREQUENCY 750 // Alapértelmezett CW dekóder frekvencia (Hz)
#define CW_DECODER_MIN_FREQUENCY 600     // Minimum CW dekóder frekvencia (Hz)
#define CW_DECODER_MAX_FREQUENCY 1500    // Maximum CW dekóder frekvencia (Hz)

//--- RTTY mód adatai
// #define RTTY_DEFAULT_MARKER_FREQUENCY 2295.0f                                      // RTTY jelölő frekvencia (Hz)
// #define RTTY_DEFAULT_SHIFT_FREQUENCY RTTY_DEFAULT_MARKER_FREQUENCY - RTTY_DEFAULT_SPACE_FREQUENCY  // RTTY eltolás frekvencia (170Hz)
// #define RTTY_DEFAULT_SPACE_FREQUENCY 2125.0f                                       // RTTY tér frekvencia (Hz)
#define RTTY_DEFAULT_MARKER_FREQUENCY 1100.0f                                                     // RTTY jelölő frekvencia (Hz)
#define RTTY_DEFAULT_SHIFT_FREQUENCY 425.0f                                                       // RTTY eltolás frekvencia (170Hz)
#define RTTY_DEFAULT_SPACE_FREQUENCY RTTY_DEFAULT_MARKER_FREQUENCY - RTTY_DEFAULT_SHIFT_FREQUENCY // RTTY space frekvencia (Hz)

//--- Array Utils ---
#define ARRAY_ITEM_COUNT(array) (sizeof(array) / sizeof(array[0]))

//--- Band Table ---
#define BANDTABLE_SIZE 30 // A band tábla mérete (bandTable[] tömb)

//--- C String compare -----
#define STREQ(a, b) (strcmp((a), (b)) == 0)

//--- Debug ---
#ifdef __DEBUG
#define DEBUG(fmt, ...) Serial.printf(fmt __VA_OPT__(, ) __VA_ARGS__)
#else
#define DEBUG(fmt, ...) // Üres makró, ha __DEBUG nincs definiálva
#endif

// Egy másodperc mikroszekundumban
#define ONE_SECOND_IN_MICROS 1000000.0f

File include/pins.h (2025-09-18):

#pragma once

// TFT (A TFT_eSPI_User_Setup.h-ban a pinout)

// I2C si4735
#define PIN_SI4735_I2C_SDA 8
#define PIN_SI4735_I2C_SCL 9
#define PIN_SI4735_RESET 10

// Audio FFT bemenet
#define PIN_AUDIO_INPUT A0 // A0/GPIO26 az FFT audio bemenethez

// Feszültségmérés
#define PIN_VBUS_EXTERNAL_MEASURE_INPUT A1 // A1/GPIO27 a VBUS mérésének feszültségosztós bemenetéhez

// Rotary Encoder
#define PIN_ENCODER_DT 17
#define PIN_ENCODER_CLK 16
#define PIN_ENCODER_SW 18

// Egyéb
#define PIN_TFT_BACKGROUND_LED 1 // A NYÁK miatt áthelyezve a  GPIO1-es lábra
#define PIN_AUDIO_MUTE 19
#define PIN_BEEPER 20

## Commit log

2025-06-29 Add rtVars and utils implementations for radio control features
    - Implemented rtVars.cpp to manage radio variables including mute status, frequency display, BFO states, and squelch settings.
    - Created utils.cpp for utility functions such as serial wait, TFT calibration, error display, beeping functions, string manipulation, and CRC16 calculation.
    - Added necessary includes and namespace organization for better code structure and readability.
2025-06-29 Implement ScreenSaver functionality, StatusLine updates, and Horizontal Button Bar
    - Added ScreenScreenSaver class to manage screen saver animations and frequency display.
    - Implemented activation and deactivation methods for the screen saver.
    - Created methods for handling animations, drawing content, and updating frequency and battery display.
    - Developed StatusLine class to display various status indicators with dynamic updates.
    - Included methods for updating BFO, AGC, mode, bandwidth, band, step, antenna capacitance, temperature, and voltage in the status line.
    - Introduced UIHorizontalButtonBar class for creating a horizontal button bar with multi-row support.
    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
2025-06-29 Implement Screen Memory Management and Virtual Keyboard Dialog
    - Added ScreenMemory class for managing FM/AM station memory, including functionalities for adding, editing, and deleting stations.
    - Implemented UI components for displaying station lists and horizontal button navigation.
    - Integrated station loading and refreshing mechanisms to keep the UI updated with current station data.
    - Developed StereoIndicator class to visually indicate stereo/mono status.
    - Created VirtualKeyboardDialog for user input with a customizable on-screen keyboard, including special keys for backspace and clear.
    - Enhanced user experience with dynamic button states and cursor visibility in the virtual keyboard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
2025-06-29 Implement ScreenAM class for AM radio functionality with specific button handling and UI management
2025-06-29 Update UIButton: correct Hungarian comment for long press event and add allowsVisualPressedFeedback method
    [UIButton.h]
2025-07-07 Add Audio Display and Analyzer Components
    - Implemented AudioDisplayComponent for visualizing audio data with various modes (spectrum, oscilloscope, waterfall).
    - Created AudioAnalyzer for processing audio input and performing FFT calculations.
    - Added support for CW/RTTY tuning and peak hold functionality.
    - Integrated touch handling for mode switching in the display component.
    - Established a global configuration reference for managing settings.
    - Enhanced debugging output for better traceability during audio processing.
2025-07-08 Refactor audio processing: remove SpectrumAnalyzer, update band filter settings, and enhance API usage in screen implementations
2025-07-09 Add DC offset calibration to AudioProcessor and remove unused comments from ScreenFM
2025-07-09 Add SpectrumVisualizationComponent for audio spectrum visualization
    - Implemented SpectrumVisualizationComponent class for displaying audio spectrum, oscilloscopes, and waterfall diagrams.
    - Added multiple display modes: Off, SpectrumLowRes, SpectrumHighRes, Oscilloscope, Waterfall, Envelope, CWWaterfall, and RTTYWaterfall.
    - Integrated touch handling for mode switching with debounce logic.
    - Implemented rendering functions for each display mode, including gradient bars and color interpolation based on intensity.
    - Added functionality for mode indicator visibility and forced redraw.
    - Included a destructor to manage sprite memory and prevent leaks.
    - Utilized mutex for safe access to shared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
2025-07-09 Add audio processing and visualization components
    - Implemented AudioProcessor class for audio data handling, FFT calculations, and various visualization modes (spectrum, oscilloscope, envelope, waterfall).
    - Created SharedAudioData structure for inter-core communication and synchronization.
    - Added SimpleSpectrumDisplay class for displaying spectrum data.
    - Developed test files for audio processing and spectrum display functionalities.
    - Included necessary headers and defined constants for audio processing.
    - Established mutex locks for thread safety during data access.
    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
2025-07-10 Add dynamic noise suppression and core processing control for EEPROM operations
    [AudioProcessor.h, main.cpp]
2025-07-10 Refactor: Adjust sample decimation factor and improve rendering flags for frequency labels
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2025-07-11 Fix: Update data availability checks in SpectrumVisualizationComponent to prevent flickering and ensure proper rendering
    [main.cpp]
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2025-07-13 Refactor AudioProcessor and related components for improved FFT handling and noise reduction
    - Introduced setSamplingFrequency method in AudioProcessor for dynamic sampling frequency adjustment.
    - Added NOISE_REDUCTION_ANALOG_SAMPLES_COUNT constant for better readability in noise reduction logic.
    - Updated FFT gain configuration references from miniAudioFftConfig to audioFftConfig in Config, DebugDataInspector, ScreenSetupAudioProc, and SpectrumVisualizationComponent.
    - Enhanced debug messages for clarity and consistency in SpectrumVisualizationComponent.
    - Removed unused methods and improved code structure for better maintainability.
    - Ensured thread-safe retrieval of FFT size and bin width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
    [AudioProcessor.h]
2025-07-13 Refactor: Remove local AudioProcessor references from SpectrumVisualizationComponent and update AudioCore1Manager for improved audio processing flow
2025-07-15 Refactor CwGoertzelDecoder and SpectrumVisualizationComponent
    - Updated CwGoertzelDecoder to include current time in processBlock method for improved timing accuracy.
    - Enhanced internal state management in CwGoertzelDecoder with additional variables for Morse code decoding.
    - Modified SpectrumVisualizationComponent constructor to initialize decoderManager and set CW parameters.
    - Adjusted frame rate for spectrum visualization to 20 FPS for better performance.
    - Consolidated rendering functions for CW and RTTY waterfalls into a single method.
    - Added helper functions for mode and frequency label rendering to improve code clarity and maintainability.
    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
2025-07-17 Enhance: Add float to string conversion utility and update AudioCore1Manager for FFT timer handling
2025-07-17 Enhance: Update timer handling in AudioCore1Manager and adjust default FFT samples in AudioProcessor
2025-07-17 Enhance: Update oscilloscope data handling in AudioCore1Manager and AudioProcessor, including sample count management
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2025-07-19 Refactor CW Decoder: Replace CwRttyDecoder with CwDecoder
    - Updated ScreenAM to include CwDecoder instead of CwRttyDecoder.
    - Removed CwRttyDecoder implementation and header files.
    - Introduced CwDecoder class with enhanced functionality for Morse code decoding.
    - Implemented adaptive thresholding and noise level calculations in CwDecoder.
    - Added state machine logic for handling Morse code timing and decoding.
    - Updated relevant includes and object instantiations in ScreenAM.
    [AudioProcessor.h]
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2025-08-03 Refactor code structure for improved readability and maintainability
    [pico-radio-5.kicad_pcb, pico-radio-5.kicad_sch]
2025-08-04 Add PicoSensorUtils for voltage and temperature readings
    - Implemented initialization function for ADC.
    - Added function to read VSYS voltage from ADC3 with caching mechanism.
    - Added function to read core temperature from ADC0 with caching mechanism.
    - Implemented cache clearing function to reset sensor values.
    - Prepared structure for potential cache status query (commented out).
    [PicoSensorUtils.cpp]
2025-08-08 Add lock files for PCB and schematic of pico-radio-5 project
    [pico-radio-5.kicad_pcb, pico-radio-5.kicad_sch]
2025-08-09 Add lock file for pico-radio-5 schematic to prevent concurrent edits
    [pico-radio-5.kicad_pcb, pico-radio-5.kicad_sch]
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2025-08-10 Fix image formatting in README.md for PCB 3D view
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2025-08-16 Add initial bill of materials for pico-radio project
    - Created a new CSV file containing the bill of materials (BOM) for the pico-radio project.
    - Included components such as transistors, capacitors, resistors, connectors, and other essential parts.
    - Specified designators, footprints, quantities, and designations for each component.
    [pico-radio-5 - bill of materials.csv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]
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2025-09-18 Fix indentation for implementation comments in UIButton, UIColorPalette, MessageDialog, and Si4735Band
    [UIButton.h, UIColorPalette.h]
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
